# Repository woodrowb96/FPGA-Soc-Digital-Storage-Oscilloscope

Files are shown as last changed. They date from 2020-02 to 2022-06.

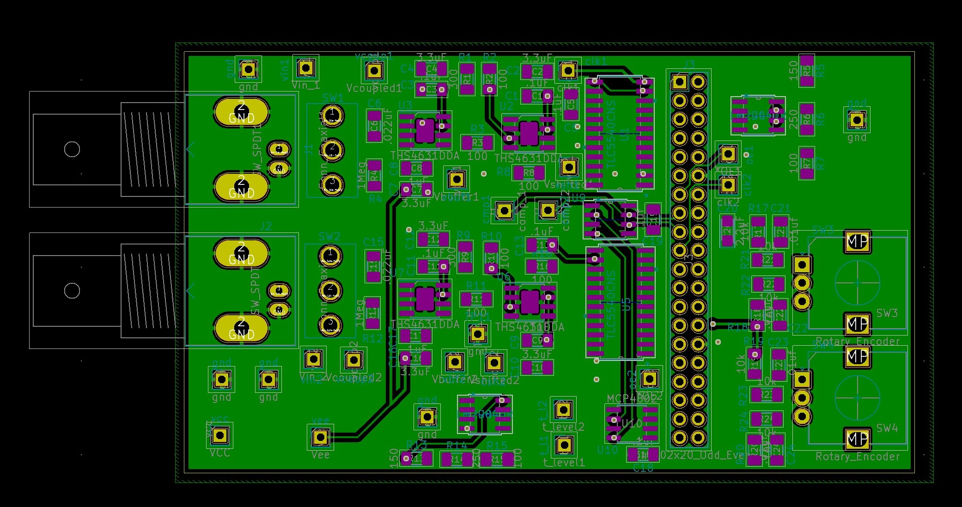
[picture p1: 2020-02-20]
Schematics and PCB/pcb back copper.jpg

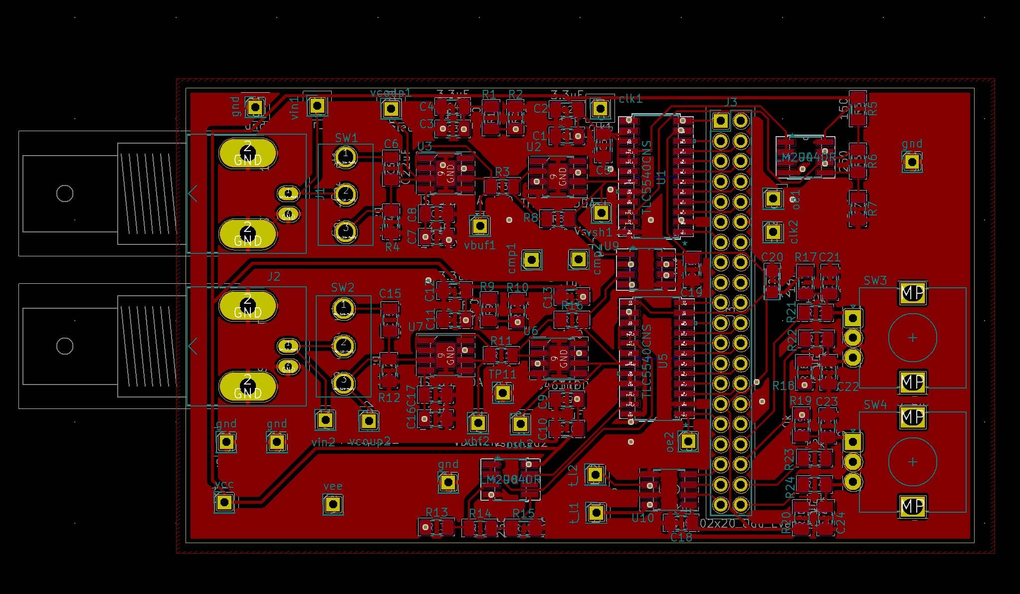
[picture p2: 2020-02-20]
Schematics and PCB/PCB Front Copper.jpg

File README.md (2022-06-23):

# Digital-Storage-Oscilloscope

This repository is for my digital storage oscilloscope project.

This project is a year long project with two other students to build a two channel digital storage oscilloscope
using the Cyclone V FPGA SOC. The FPGA half of the chip is used to aquire data, and the Soc(called the HPS in documentation) half of the chip is used to display that dat onto a GUI. The two halfs of the chip communicate over a pair of axi bridges. These bridges let the FPGA access HPS memory, and give the Soc access to registers on the FPGA.  This is a yearlong project and is ongoing. The project will be complete during spring term 2020. 

ghrd_top.sv is the top level module for the logic on the FPGA.

soc_system.qsys is the qsys system for this project.

soc_system.v is the top level module for the qsys system.

Code for each module is split into folders.

There is also a folder with a schematic and PCB gerbers I designed for this project. 

Bellow is a more in depth overview of the project and what I did for it. 

I am responsible for three blocks within the system. The analog front end block, the trigger block, 
and the data aquesition controll logic block.

The analog front end block is repsonsible for filtering the two analog voltages that we are measuring with the scope, and for sending
those voltages into adc's to be sampled. This block is completely on the PCB.

The trigger block is used to generate a trigger signal, that is used by the data acquisition control logic block to trigger the signals we are measuring. This block is partially on the PCB and partially on the FPGA. On the PCB there is a DAC and comparator. The DAC is used to generate a trigger voltage that is sent to a comparator. The DAC is controlled over SPI by the FPGA. The comparator compares the trigger voltage and the analog voltage of the wave we are measuring, and outputs a signal that is sent to the data aq contnrol logic block. There is also a pair of rotary encoders that are used to change the trigger level.
On the FPGA there is logic which decodes the Rotary encoders, and that interfaces with the DAC over SPI.

The data acquesition block is responsible for storing data into memory that can be accesed by the Soc and displayed on a GUI. 
Inside this block there is a state machine that controlles the triggering process. This state machine looks at the trigger signal and
uses it to determine how data is stored in memory. The memory used to store data is in the form of on chip dual port block ram within the FPGA. One port of the RAM is used by the FPGA to wirte samples into memory. This port is connected to a memory controller, which is controlled by the trigger state machine. The other port of the RAM is connected to the HPS through one of the HPS FPGA interfaces, and is used to let the soc read sample data out of memory to be displayed on the GUI. A description of the FPGA Soc interface is given bellow. 

The HPS and FPGA interface through three axi bridges. An FPGA-to-HPS bridge, a heavywieght HPS-to-FPGA bridge and a lightweight HPS-to-FPGA bridge. The on chip RAM is connected to the HPS through the  lightweight H2F bridge. This bridge is made up of slaves on the FPGA which are mastered by the HPS through the AXI bridge. This bridge lets the HPS read from and write to registers on the FPGA. In our design one port of the on chip RAM is connected to the h2f slaves on the FPGA, and can be read through the h2f lightweight axi bridge by the HPS. The adress space of the on chip RAM is mapped to a virtual address space, that can be pointed to by code on the HPS. 

top_level

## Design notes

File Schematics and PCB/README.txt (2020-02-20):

This folder has pictures of the schematic for the circuit I desisgned for the analog front end and trigger blocks in the system.

The analog front end circuit has two op amps. The first is used to buffer the signal and create a 1Meg input resistance to the scope. 
This 1Meg input resistance is used with the scope probes to create the x1 and x10 attenuation modes. The second op amp is used as a level 
shifter. This level shifter shifts the signal up by Vcc/2 and inverts it. This is used to make sure the signal we are measuring is positve when
it goes into the ADC. The equation for the level shifter transformation is Vout = Vcc/2 - Vin.

There is also a coupling capacitor at the input that is used to switch the scope between AC and DC coupling modes.

The trigger circuit has a DAC and comparator that are used to generate a trigger signal and trigger the signal.

There is also a picure and gerber files for a PCB that I designed and built to test these blocks.

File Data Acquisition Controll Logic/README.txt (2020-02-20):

This folder contains the SystemVerilog code for the data acquisiton control logic block. 

Inside this block there is a state machine that controlls the acquisition process. There is also a counter that is used by the 
state machine to count clock cycles. Finally there is a memory controller block, that is cotrolled by the state machine and that
stores samples from the adc into memory.

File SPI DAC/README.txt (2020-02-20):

This module is controlles the DAC's used in the trigger for the scope.

This block decodes a pair of roatary encoders, that are used to set the 
reference level in the DAC's. This ref level is sent over SPI to the DAC.

Data used to set the output of the DAC is sent using SPI. 
The spi_mosi module only has the master out part implemented, since
there is no need to read data from the DAC's.

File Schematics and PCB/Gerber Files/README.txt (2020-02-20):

This folder has the Gerber files for the PCB

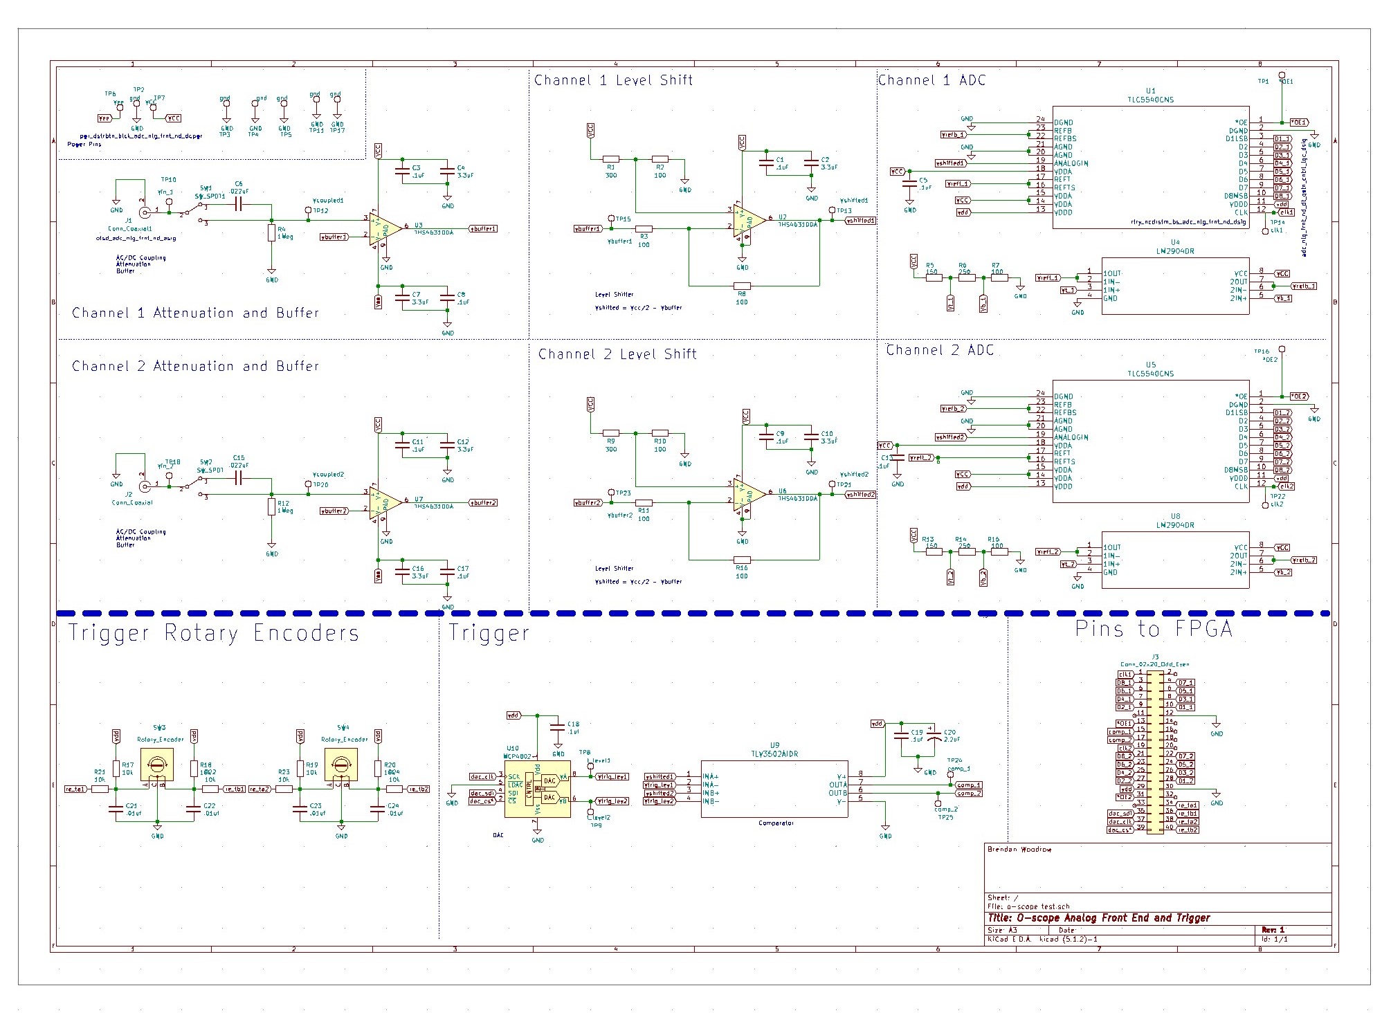
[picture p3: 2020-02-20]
Schematics and PCB/analog front end and trigger schematic.jpg

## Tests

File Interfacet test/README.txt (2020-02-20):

This folder has code for an interface testing module.

This module was used to help me debug and test my blocks in the system.

This module generates an adc_clk, and lets me change the frequency of the clk. 
The adc_clk has an enable that lets me test my data_aq state machine.

This module also displayes the stream of samples from the adc onto a seven seg display.

interface_test.sv is the top level module

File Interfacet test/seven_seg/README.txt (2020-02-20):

This is code to drive a seven segement display. That was used to debuge.

This module works with negetive numbers. 

multiplexer.sv has logic to decode 2's compliment numbers

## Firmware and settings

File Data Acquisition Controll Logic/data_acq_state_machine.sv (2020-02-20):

/* 
This state machine is used to controll the data acquisition process.

This SM looks at the trigger signal and uses it to determine how samples should be placed in memory

*/


module data_acq_state_machine(
	
	input logic clk,
	input logic reset_n,
	input logic trigger,
	input logic [16:0] address,
	input logic [15:0] count,
	output logic restart_count_n,
	output logic adc_clk_enable_n,
	output logic restart_mem_n

);
	parameter not_trig = 2'd0;	//not triggered, load samples in to memory, repeat until trigger
	parameter re_sample = 2'd1;	//after trigger, resample the signal, too get a sample that is after trigger point 
	parameter triggered = 2'd2;	//in trigger mode load 100k smaples into memory starting at address 0, 
	parameter re_trig = 2'd3;		//once 100k samples are in memory, wait for 10000 adc_clk cycles for another trigger
											//if a trigger happens go back to trigger mode, if not go to non triggered mode
	
	logic [1:0] state;
	logic [1:0] next_state;
	logic [1:0] trigger_register;
	logic trigger_condition;
	
	
	
	always_ff@(posedge clk)		//clock trigger into flip flops
		begin
			trigger_register <= {trigger_register[0],trigger};
		
		end
		
	
	
	always_comb		//check for trigger condition
		begin
			trigger_condition = (~trigger_register[0]) & trigger_register[1]); //sense the falling edge of the trigger signal
		end
	
	
	
	
	always_ff@(posedge clk, negedge reset_n)//state reg
		begin
			if(~reset_n)
				begin
					state <= not_trig;
				end
			else
				begin
					state <= next_state;
				end
		end
		
	
	
	
	always_comb	//next state logic
		begin
			case(state)
				not_trig:begin//case
					
					if( trigger_condition)	//if there is a trigg condition go to re sample
						begin
							next_state = re_sample;
						end
					else					//else stay in this state till trigger condition
						begin
							next_state = not_trig;
						end
						
				end//case
				
				re_sample:next_state = triggered;		//re sample and go to trigger state
				
				triggered:begin//case
					
					if(address == 17'd102399)	//when address is at 102399, we have filled memory
						begin
							next_state = re_trig;		//go to re_trig and try and re trigger signal
						end
					else
						begin
							next_state = triggered;			//stay in this stay until memory is full
						end
						
				end//case
				
				re_trig:begin//case
					
					if(trigger_condition)		//if trigger condition,  resample and start storing samples in memory
						begin
							next_state = re_sample;
						end
					else if(count ==	16'd1000)	//if we have timed out, go back to not_trig state
						begin
							next_state = not_trig;
						end
					else
						begin
							next_state = re_trig;		
						end
				
				end//case
				default: next_state = not_trig;
			endcase
		end
		
	always_comb	//output logic
		begin
			case(state)
				not_trig:begin//case
					
					restart_count_n = 1'b1;
					adc_clk_enable_n = 1'b1;
					restart_mem_n = 1'b1;
					
				end//case
				re_sample:begin//case
				
					restart_count_n = 1'b1;
					adc_clk_enable_n = 1'b0;	//disable adc_clk, to resample
					restart_mem_n = 1'b0;		//restart memory controller to address 0,while reset is low
														//nothing will be loaded in memory
					
				end//case
				triggered:begin//case
				
					restart_count_n = 1'b0;		//restart count, for re_trig state 
					adc_clk_enable_n = 1'b1;
					restart_mem_n = 1'b1;
					
				end//case
				re_trig:begin//case
				
					restart_count_n = 1'b1;
					adc_clk_enable_n = 1'b1;
					restart_mem_n = 1'b0;		//disable and restart memory controller to address 0,
					
				end//case
				default:begin//case
					
					restart_count_n = 1'b0;
					adc_clk_enable_n = 1'b0;
					restart_mem_n = 1'b0;
					
				end//case
			endcase;
			
		end


endmodule 

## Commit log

2020-02-20 Create SPI DAC
2020-02-20 Rename ADC Analog Front End and Trigger Schematics/README.txt to ADC Analog Front End and Trigger Schematics and PCB/README.txt
2020-02-20 Rename ADC Analog Front End and Trigger Schematics and PCB/README.txt to Schematics and PCB/README.txt
